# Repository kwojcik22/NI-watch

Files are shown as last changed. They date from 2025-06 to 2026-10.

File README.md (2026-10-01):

# NI-watch

NI-watch is an embedded watch project based on the STM32F0 MCU family. The firmware is designed for a custom hardware platform with RTC support, button input, LED feedback, alarm management, and UART-based debug logging.

## Post-production Images

  Top and bottom photos exported from the post-production media folder:

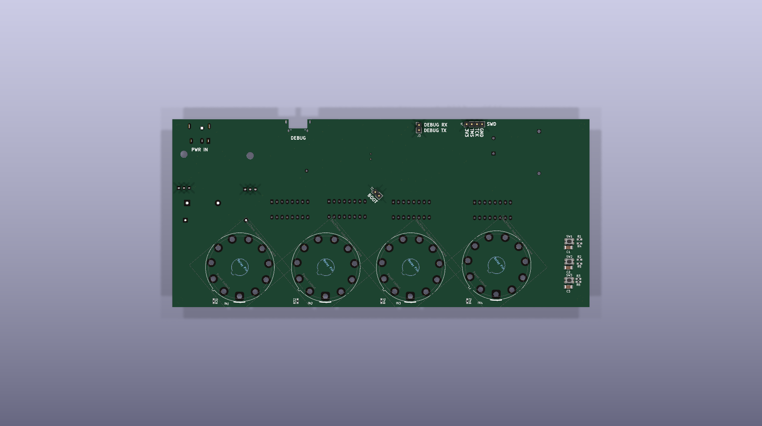
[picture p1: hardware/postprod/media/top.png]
Top view
  

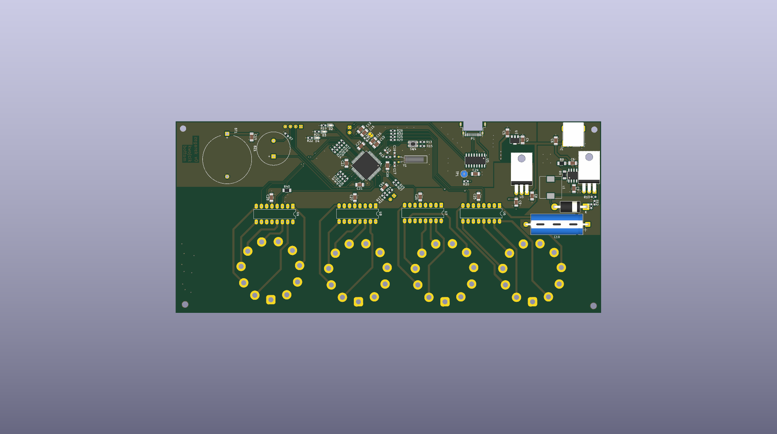
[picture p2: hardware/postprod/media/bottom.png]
Bottom view
  

## Project Structure

A compact overview of the main repository layout:

```text
NI-watch/
├── hardware/
│   ├── doc/
│   └── zegarek/
│       ├── fp-lib-table
│       ├── jlcpcb/
│       │   └── production_files/
│       ├── Library.pretty/
│       ├── MCU.kicad_sch
│       ├── NIXIE.kicad_sch
│       ├── PWR_MNG.kicad_sch
│       ├── zegarek.kicad_pcb
│       ├── zegarek.kicad_prl
│       ├── zegarek.kicad_pro
│       ├── zegarek.kicad_sch
├── README.md
└── software/
    └── TheWatch/
        ├── Core/
        │   ├── Inc/
        │   │   ├── bsp/
        │   │   ├── logger/
        │   │   └── Manager/
        │   └── Src/
        ├── Debug/
        ├── Drivers/
        ├── STM32F091RCTX_FLASH.ld
        ├── TheWatch Debug.launch
        └── TheWatch.ioc
```

The main firmware path is `software/TheWatch/Core/`, where the primary application, peripheral drivers, and helpers are located.

## Hardware Status

The `hardware/` folder contains the KiCad board project and the JLCPCB manufacturing export data for the watch design.

- `hardware/zegarek/zegarek.kicad_pcb` is the PCB layout file.
- The project includes additional schematic sheets for the MCU and power sections: `MCU.kicad_sch`, `NIXIE.kicad_sch`, and `PWR_MNG.kicad_sch`.
- `hardware/zegarek/Library.pretty/` contains custom local footprint libraries used by the design.
- `hardware/zegarek/jlcpcb/` contains fabrication outputs and assembly data exported for JLCPCB.
  - `hardware/zegarek/jlcpcb/production_files/gerber.zip` contains the generated Gerber files for board manufacturing.
  - `hardware/zegarek/jlcpcb/production_files/` contains the exported BOM and CPL files for assembly.

## MCU Peripherals

The table below lists only the MCU peripherals used by the firmware and their primary roles.

| Peripheral | Usage | Pins / Notes |
|---|---|---|
| RTC | Timekeeping, Alarm A | on-chip RTC |
| GPIO (Buttons) | User input (short/long press) | USER: `GPIOA/B` |
| LEDs | debug feedback & heartbeat | `GPIO_LED0/1/2` |
| UART | Debug logging (logger) | USART (see `usart.c`) |
| Timers | Heartbeat, alarm buzzer and non-blocking timers | TIMx (system timers) |

## Features

- 24-hour RTC operation using the on-chip RTC peripheral
- Alarm support using RTC Alarm A
- Button press detection with short press and long press events
- LED toggling for user feedback and heartbeat status
- UART logging for debug and runtime information

## User Interaction

### Buttons

- Blue button (configured on GPIOC pin 13)
  - Short press: read current RTC time and print it to the logger
  - Long press: set the RTC alarm to one minute ahead of the current time and log the alarm value
- Additional buttons on GPIOA and GPIOB toggle onboard LEDs for quick manual feedback

### LEDs

- LEDs connected to `GPIO_LED0`, `GPIO_LED1`, and `GPIO_LED2` toggle when their respective buttons are pressed
- `LD2` is toggled periodically by a non-blocking timer to provide a simple heartbeat indicator

## RTC and Alarm Behavior

- RTC is initialized with default time and date values
- Alarm A is enabled at startup and can be updated by user input
- Alarm behavior and interrupt handling are logged through the UART debug logger

## Debugging and Logging

- Logging is implemented through `logger/logger.h` and `logger/logger.c`
- Log levels include `INFO`, `WARN`, `ERROR`, and `DEBUG`
- The firmware prints time reads, alarm configuration, button events, and interrupt notices

## Build Notes

- The firmware is built using STM32Cube-generated HAL code and project files
- The target MCU is an STM32F091RCTX device
- `software/TheWatch/STM32F091RCTX_FLASH.ld` contains the linker script for flash layout

## Notes

This README describes the current firmware behavior as implemented in the provided source files. The project is a work in progress and can be extended with additional watch features such as display output, time setting via buttons

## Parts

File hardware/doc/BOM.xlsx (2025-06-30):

Reference | Value | Datasheet | Footprint | Qty | DNP
POJEMNOŚCI
C1 | 100nF | ~ | Capacitor_SMD:C_1206_3216Metric_Pad1.33x1.80mm_HandSolder | 1 | OK.
C2 | 1nF | ~ | Capacitor_SMD:C_1206_3216Metric_Pad1.33x1.80mm_HandSolder | 1 | OK.
C3 | 4u7 250V MPEM-4U7R27.5/250 | https://www.tme.eu/pl/details/mpem-4u7r27.5_250/kondensatory-foliowe-tht/sr-passives/ | Capacitor_THT:CP_Axial_L25.0mm_D10.0mm_P30.00mm_Horizontal | 1 | OK.
PÓŁPRZEWODNIKI
D1 | UF5400 | https://www.tme.eu/pl/details/uf4007-dio/diody-uniwersalne-tht/diotec-semiconductor/uf4007/ | Diode_THT:D_DO-201AD_P15.24mm_Horizontal | 1 | OK.
Q1 | IRF740PBF | https://www.tme.eu/pl/details/irf740pbf/tranzystory-z-kanalem-n-tht/vishay/ | Package_TO_SOT_THT:TO-220-3_Vertical | 1 | OK.
KONEKTORY
J1 | Conn_01x02_Socket | ~ | Connector:Banana_Jack_2Pin | 1 | OK.
J2 | Conn_01x02_Socket | ~ | Connector:Banana_Jack_2Pin | 1 | OK.
INDUKCYJNE
L1 | 100uH smd 800mA SD8328-101-R | https://www.tme.eu/pl/details/sd8328-101-r/dlawiki-smd-mocy/eaton-electronics/ | Inductor_SMD:L_10.4x10.4_H4.8 | 1 | OK.
REZYSTORY
R1 | 0R22 thic film prec. | https://www.tme.eu/pl/details/cs1206-0.22r-1%25/rezystory-smd/royal-ohm/cs06w4f220lt5e/ | Resistor_SMD:R_1206_3216Metric_Pad1.30x1.75mm_HandSolder | 1 | OK.
R2 | 180 | ~ | Resistor_SMD:R_0805_2012Metric | 1 | OK.
R3 | 330 | ~ | Resistor_SMD:R_0805_2012Metric_Pad1.20x1.40mm_HandSolder | 1 | OK.
R4 | 150k | ~ | Resistor_SMD:R_0805_2012Metric_Pad1.20x1.40mm_HandSolder | 1 | OK.
R5 | 1k | ~ | Resistor_SMD:R_0805_2012Metric_Pad1.20x1.40mm_HandSolder | 1 | OK.
UKŁADY SCALONE
U1 | MC34063ADR | https://www.tme.eu/pl/details/mc34063adr/regulatory-napiecia-uklady-dc-dc/texas-instruments/ | Package_SO:SOIC-8_3.9x4.9mm_P1.27mm | 1 | OK.
MECHANICZNE
 | dystans m3 | https://www.tme.eu/pl/details/fix-mae-15tv/kolki-montazowe-plastikowe/fix-fasten/ |  | 4 | OK.
 | śrubka M3 | _ |  | 5 | OK.
 | radiator M3 | https://www.tme.eu/pl/details/ua17-to220/radiatory/fischer-elektronik/sk13-35-al-220/ |  | 1 | OK.

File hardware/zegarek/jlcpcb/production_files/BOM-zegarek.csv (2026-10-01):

Comment | Designator | Footprint | LCSC | Quantity
Battery_Cell | BT1 | BatteryHolder_MYOUNG_BS-07-A1BJ001_CR2032 | C964750 | 1
Buzzer | BZ1 | MagneticBuzzer_StarMicronics_HMB |  | 1
100n | C1,C12,C14,C16,C19,C2,C20,C21,C22,C23,C24,C25,C26,C27,C28,C3,C5,C9 | C_1206_3216Metric_Pad1.33x1.80mm_HandSolder | C152824 | 18
4u7 250V | C10 | CP_Axial_L25.0mm_D10.0mm_P30.00mm_Horizontal |  | 1
10u | C11,C15 | C_1206_3216Metric_Pad1.33x1.80mm_HandSolder | C49326738 | 2
100n | C13 | C_0603_1608Metric_Pad1.08x0.95mm_HandSolder | C1590 | 1
4.3p | C17,C18 | C_0603_1608Metric_Pad1.08x0.95mm_HandSolder | C424850 | 2
0.33u | C4,C8 | C_1206_3216Metric_Pad1.33x1.80mm_HandSolder | C274377 | 2
100nF | C6 | C_1206_3216Metric_Pad1.33x1.80mm_HandSolder | C152824 | 1
1nF | C7 | C_1206_3216Metric_Pad1.33x1.80mm_HandSolder | C49326757 | 1
UF4007 | D1 | D_DO-201AD_P15.24mm_Horizontal | C54426167 | 1
LED | D2 | LED_0603_1608Metric_Pad1.05x0.95mm_HandSolder | C89811 | 1
LED | D3 | LED_0603_1608Metric_Pad1.05x0.95mm_HandSolder | C2286 | 1
LED | D4 | LED_0603_1608Metric_Pad1.05x0.95mm_HandSolder | C2288 | 1
BLM18AG121SN1 | FB1 | L_0603_1608Metric_Pad1.05x0.95mm_HandSolder | C76892 | 1
~ | IN1 | IN-14 NIXIE TUBE |  | 1
~ | IN2 | IN-14 NIXIE TUBE |  | 1
~ | IN3 | IN-14 NIXIE TUBE |  | 1
~ | IN4 | IN-14 NIXIE TUBE |  | 1
Barrel_Jack_MountingPin | J1 | BarrelJack_CUI_PJ-079BH_Horizontal |  | 1
Conn_01x02 | J2,J3 | PinHeader_1x02_P2.54mm_Vertical | C86471 | 2
Conn_01x04 | J4 | PinHeader_1x04_P2.54mm_Vertical | C124378 | 1
Jumper_2_Small_Bridged | JP1 | SolderJumper-2_P1.3mm_Bridged_RoundedPad1.0x1.5mm |  | 1
100uH | L1 | L_10.4x10.4_H4.8 | C2045483 | 1
USB_C_Plug_USB2.0 | P1 | USB_C_Receptacle_Amphenol_12401948E412A | C53185062 | 1
IRF740 | Q1 | TO-220-3_Horizontal_TabUp | C358408 | 1
1k | R1,R12,R13,R3,R7 | R_0603_1608Metric_Pad0.98x0.95mm_HandSolder | C2074140 | 5
330 | R10 | R_0603_1608Metric_Pad0.98x0.95mm_HandSolder | C23138 | 1
150k | R11 | R_0603_1608Metric_Pad0.98x0.95mm_HandSolder | C22807 | 1
10k | R14,R16 | R_0603_1608Metric_Pad0.98x0.95mm_HandSolder | C15401 | 2
4k7 | R15,R20,R4,R5,R6 | R_0603_1608Metric_Pad0.98x0.95mm_HandSolder | C3152147 | 5
510k | R17 | R_0603_1608Metric_Pad0.98x0.95mm_HandSolder | C23192 | 1
220 | R18,R19,R21,R22 | R_0603_1608Metric_Pad0.98x0.95mm_HandSolder | C54920883 | 4
1k | R2 | R_0603_1608Metric_Pad0.98x0.95mm_HandSolder |  | 1
100 | R23,R24,R25,R26,R27,R28,R29,R30,R33,R34,R35,R36,R37,R38,R39 | R_0603_1608Metric_Pad0.98x0.95mm_HandSolder | C3152153 | 15
15k | R31,R32,R41,R42 | R_0603_1608Metric_Pad0.98x0.95mm_HandSolder | C22809 | 4
100 | R40 | R_1206_3216Metric_Pad1.30x1.75mm_HandSolder | C17901 | 1
0R22 | R8 | R_1206_3216Metric_Pad1.30x1.75mm_HandSolder |  | 1
180 | R9 | R_1206_3216Metric_Pad1.30x1.75mm_HandSolder | C17924 | 1
SW_Push | SW1 | SW_Push_1P1T_NO_CK_KMR2 |  | 1
SW_Push | SW2 | SW_Push_1P1T_NO_CK_KMR2 |  | 1
SW_Push | SW3 | SW_Push_1P1T_NO_CK_KMR2 |  | 1
SW_Push | SW4 | SW_Push_1P1T_NO_CK_KMR2 |  | 1
DEBUG RST | TP1 | TestPoint_Loop_D2.60mm_Drill0.9mm_Beaded |  | 1
DI78L3.3UAB | U1 | SOT-89-3 |  | 1
MC34063AD | U2 | SOIC-8_3.9x4.9mm_P1.27mm | C2873086 | 1
L7805ACV | U3 | TO-220-3_Horizontal_TabUp | C192854 | 1
STM32F091RCTx | U4 | LQFP-64_10x10mm_P0.5mm | C89056 | 1
CH340C | U5 | SOIC-16_3.9x9.9mm_P1.27mm | C84681 | 1
74141 | U6 | CERDIP-16_W7.62mm_SideBrazed_LongPads |  | 1
74141 | U7 | CERDIP-16_W7.62mm_SideBrazed_LongPads |  | 1
74141 | U8 | CERDIP-16_W7.62mm_SideBrazed_LongPads |  | 1
74141 | U9 | CERDIP-16_W7.62mm_SideBrazed_LongPads |  | 1
32.768kHz | Y1 | Crystal_AT310_D3.0mm_L10.0mm_Horizontal | C2236 | 1

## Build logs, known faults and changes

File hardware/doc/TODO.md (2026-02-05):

[ ] - zmieniono C2 na mniejszy (biały chyba 200pF), czy 100V było też na 200p czy tylko na 100p?
[ ] - 150k R4 zostaje 150k
[ ] - 1k R5 dopasować na potencjometrze != 0ohm

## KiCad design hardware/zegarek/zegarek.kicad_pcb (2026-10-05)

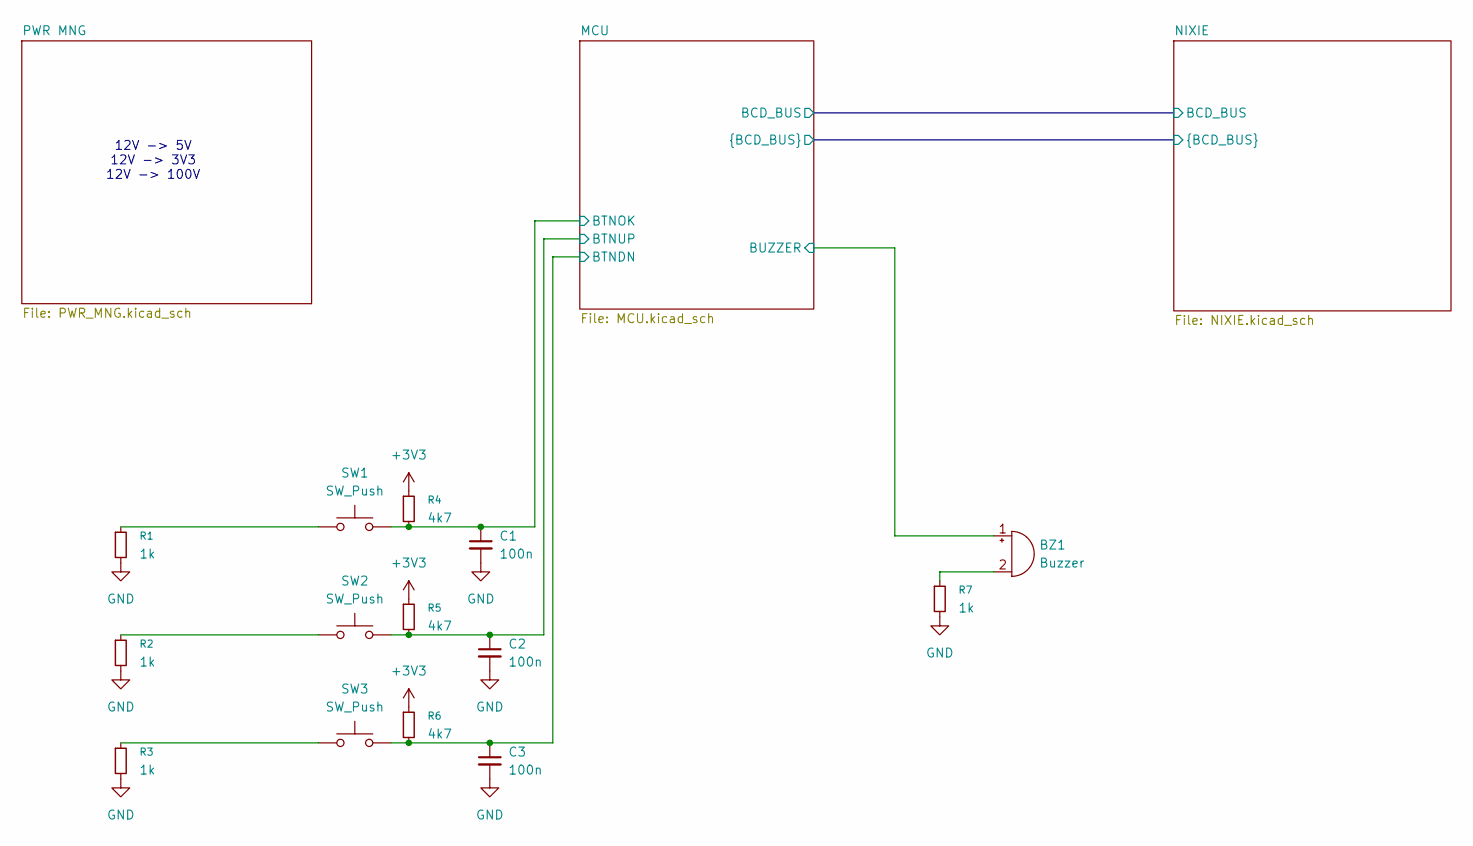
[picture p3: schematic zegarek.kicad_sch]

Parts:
BZ1: Buzzer; MagneticBuzzer_StarMicronics_HMB
C1, C2, C3: 100n; C_1206_3216Metric_Pad1.33x1.80mm_HandSolder; LCSC C152824
R1, R3, R7: 1k; R_0603_1608Metric_Pad0.98x0.95mm_HandSolder; LCSC C2074140
R2: 1k; R_0603_1608Metric_Pad0.98x0.95mm_HandSolder
R4, R5, R6: 4k7; R_0603_1608Metric_Pad0.98x0.95mm_HandSolder; LCSC C3152147
SW1, SW2, SW3: SW_Push; SW_Push_1P1T_NO_CK_KMR2

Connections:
+3V3: R4.1, R5.1, R6.1; also elsewhere on the board
/MCU/BTNDN: C3.1, R6.2, SW3.2; also elsewhere on the board
/MCU/BTNOK: C1.1, R4.2, SW1.2; also elsewhere on the board
/MCU/BTNUP: C2.1, R5.2, SW2.2; also elsewhere on the board
/MCU/BUZZER: BZ1.1 (+); also elsewhere on the board
GND: C1.2, C2.2, C3.2, R1.2, R2.2, R3.2, R7.2; also elsewhere on the board
unnamed: BZ1.2 (-), R7.1
unnamed: R1.1, SW1.1
unnamed: R2.1, SW2.1
unnamed: R3.1, SW3.1

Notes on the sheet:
12V -> 5V 12V -> 3V3 12V -> 100V

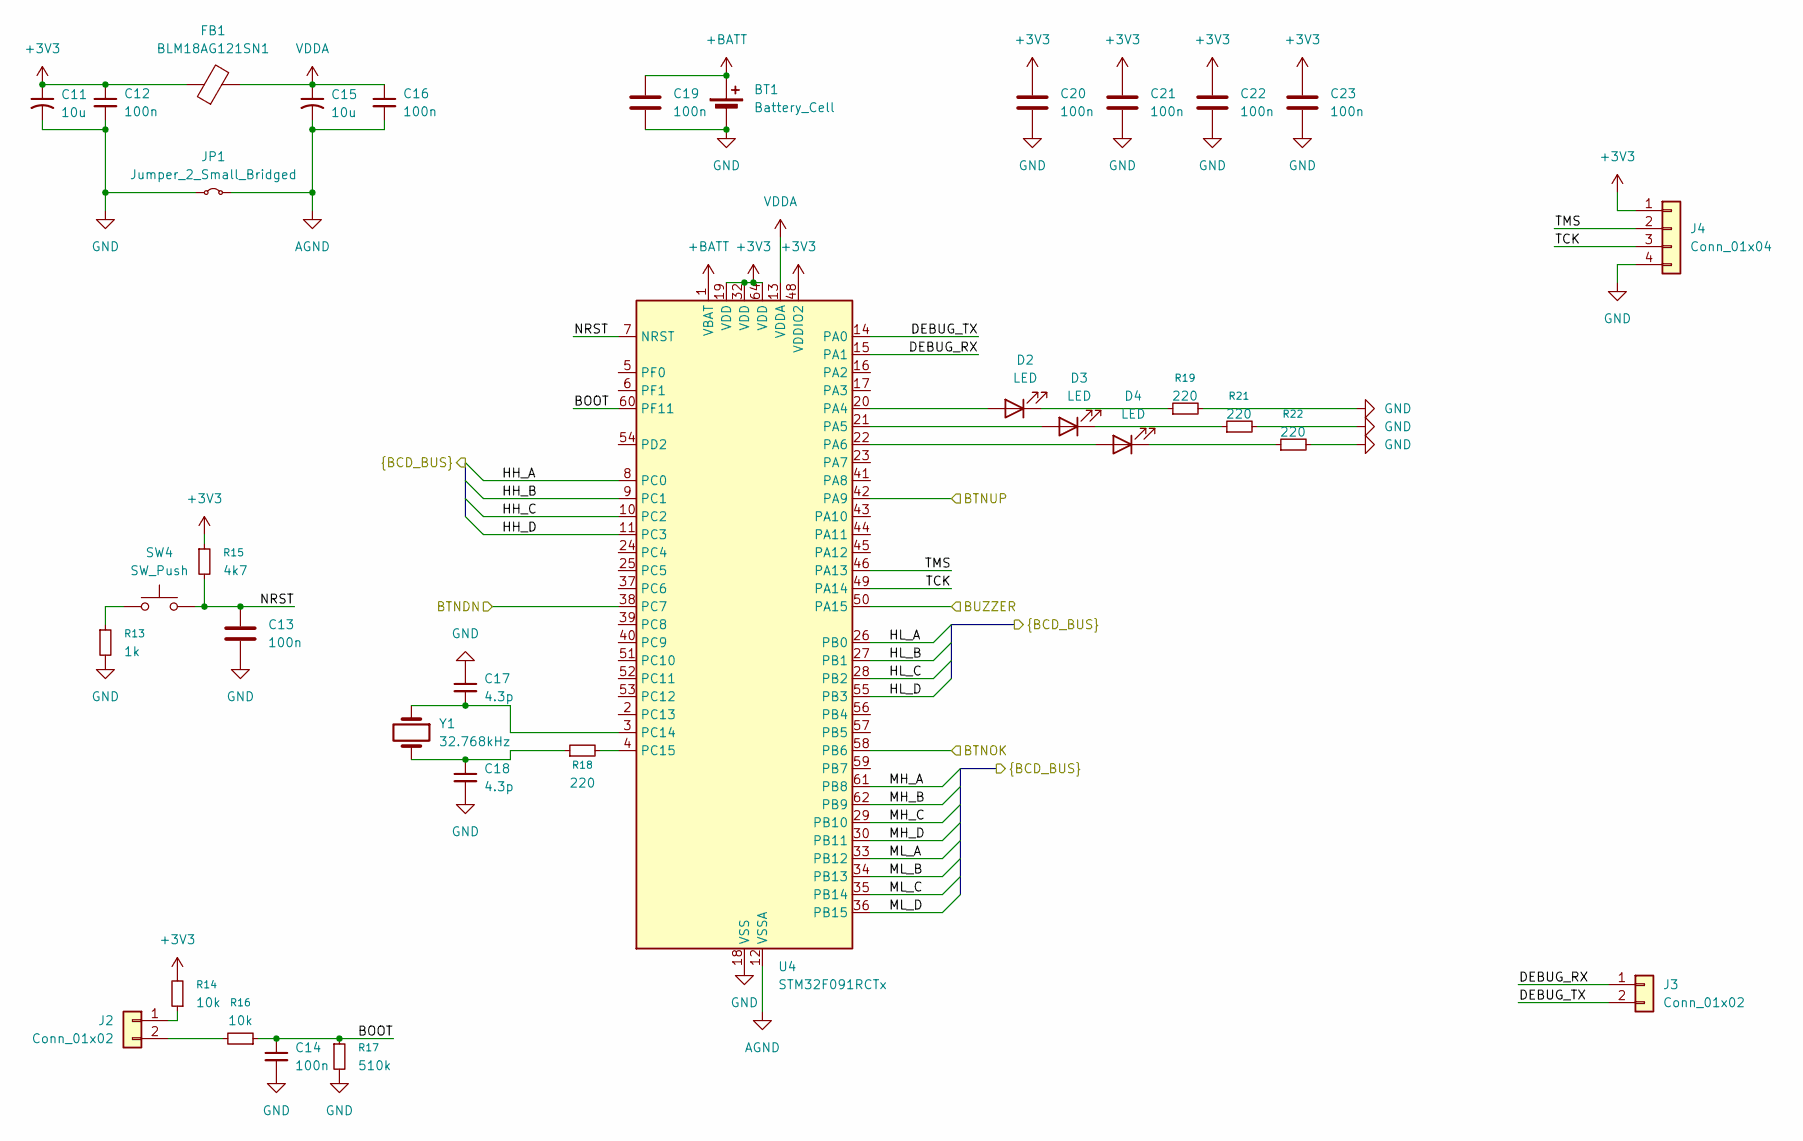
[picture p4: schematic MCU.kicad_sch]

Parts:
BT1: Battery_Cell; BatteryHolder_MYOUNG_BS-07-A1BJ001_CR2032; LCSC C964750
C11, C15: 10u; C_1206_3216Metric_Pad1.33x1.80mm_HandSolder; LCSC C49326738
C12, C14, C16, C19, C20, C21, C22, C23: 100n; C_1206_3216Metric_Pad1.33x1.80mm_HandSolder; LCSC C152824
C13: 100n; C_0603_1608Metric_Pad1.08x0.95mm_HandSolder; LCSC C1590
C17, C18: 4.3p; C_0603_1608Metric_Pad1.08x0.95mm_HandSolder; LCSC C424850
D2: LED; LED_0603_1608Metric_Pad1.05x0.95mm_HandSolder; LCSC C89811
D3: LED; LED_0603_1608Metric_Pad1.05x0.95mm_HandSolder; LCSC C2286
D4: LED; LED_0603_1608Metric_Pad1.05x0.95mm_HandSolder; LCSC C2288
FB1: BLM18AG121SN1; L_0603_1608Metric_Pad1.05x0.95mm_HandSolder; LCSC C76892
J2, J3: Conn_01x02; PinHeader_1x02_P2.54mm_Vertical; LCSC C86471
J4: Conn_01x04; PinHeader_1x04_P2.54mm_Vertical; LCSC C124378
JP1: Jumper_2_Small_Bridged; SolderJumper-2_P1.3mm_Bridged_RoundedPad1.0x1.5mm
R13: 1k; R_0603_1608Metric_Pad0.98x0.95mm_HandSolder; LCSC C2074140
R14, R16: 10k; R_0603_1608Metric_Pad0.98x0.95mm_HandSolder; LCSC C15401
R15: 4k7; R_0603_1608Metric_Pad0.98x0.95mm_HandSolder; LCSC C3152147
R17: 510k; R_0603_1608Metric_Pad0.98x0.95mm_HandSolder; LCSC C23192
R18, R19, R21, R22: 220; R_0603_1608Metric_Pad0.98x0.95mm_HandSolder; LCSC C54920883
SW4: SW_Push; SW_Push_1P1T_NO_CK_KMR2
U4: STM32F091RCTx; LQFP-64_10x10mm_P0.5mm; LCSC C89056
Y1: 32.768kHz; Crystal_AT310_D3.0mm_L10.0mm_Horizontal; LCSC C2236

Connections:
+3V3: C11.1, C12.1, C20.1, C21.1, C22.1, C23.1, FB1.1, J4.1, R14.2, R15.1, U4.19 (VDD), U4.32 (VDD), U4.48 (VDDIO2), U4.64 (VDD); also elsewhere on the board
+BATT: BT1.1 (+), C19.1, U4.1 (VBAT)
/MCU/BOOT: C14.1, R16.1, R17.1, U4.60 (PF11)
/MCU/BTNDN: U4.38 (PC7); also elsewhere on the board
/MCU/BTNOK: U4.58 (PB6); also elsewhere on the board
/MCU/BTNUP: U4.42 (PA9); also elsewhere on the board
/MCU/BUZZER: U4.50 (PA15); also elsewhere on the board
/MCU/DEBUG_RX: J3.1, U4.15 (PA1)
/MCU/DEBUG_TX: J3.2, U4.14 (PA0)
/MCU/HH_A: U4.8 (PC0); also elsewhere on the board
/MCU/HH_B: U4.9 (PC1); also elsewhere on the board
/MCU/HH_C: U4.10 (PC2); also elsewhere on the board
/MCU/HH_D: U4.11 (PC3); also elsewhere on the board
/MCU/HL_A: U4.26 (PB0); also elsewhere on the board
/MCU/HL_B: U4.27 (PB1); also elsewhere on the board
/MCU/HL_C: U4.28 (PB2); also elsewhere on the board
/MCU/HL_D: U4.55 (PB3); also elsewhere on the board
/MCU/MH_A: U4.61 (PB8); also elsewhere on the board
/MCU/MH_B: U4.62 (PB9); also elsewhere on the board
/MCU/MH_C: U4.29 (PB10); also elsewhere on the board
/MCU/MH_D: U4.30 (PB11); also elsewhere on the board
/MCU/ML_A: U4.33 (PB12); also elsewhere on the board
/MCU/ML_B: U4.34 (PB13); also elsewhere on the board
/MCU/ML_C: U4.35 (PB14); also elsewhere on the board
/MCU/ML_D: U4.36 (PB15); also elsewhere on the board
/MCU/NRST: C13.1, R15.2, SW4.2, U4.7 (NRST)
/MCU/TCK: J4.3, U4.49 (PA14)
/MCU/TMS: J4.2, U4.46 (PA13)
AGND: C15.2, C16.2, JP1.2 (B), U4.12 (VSSA)
GND: BT1.2 (-), C11.2, C12.2, C13.2, C14.2, C17.1, C18.2, C19.2, C20.2, C21.2, C22.2, C23.2, J4.4, JP1.1 (A), R13.2, R17.2, R19.2, R21.2, R22.2, U4.18 (VSS), U4.31 (VSS), U4.47 (VSS), U4.63 (VSS); also elsewhere on the board
unnamed: C18.1, R18.1, Y1.2
unnamed: D2.2 (A), U4.20 (PA4)
unnamed: D2.1 (K), R19.1
unnamed: D3.2 (A), U4.21 (PA5)
unnamed: D3.1 (K), R21.1
unnamed: D4.2 (A), U4.22 (PA6)
unnamed: D4.1 (K), R22.1
unnamed: J2.1, R14.1
unnamed: J2.2, R16.2
unnamed: R13.1, SW4.1
unnamed: C17.2, U4.3 (PC14), Y1.1
unnamed: R18.2, U4.4 (PC15)
VDDA: C15.1, C16.1, FB1.2, U4.13 (VDDA)

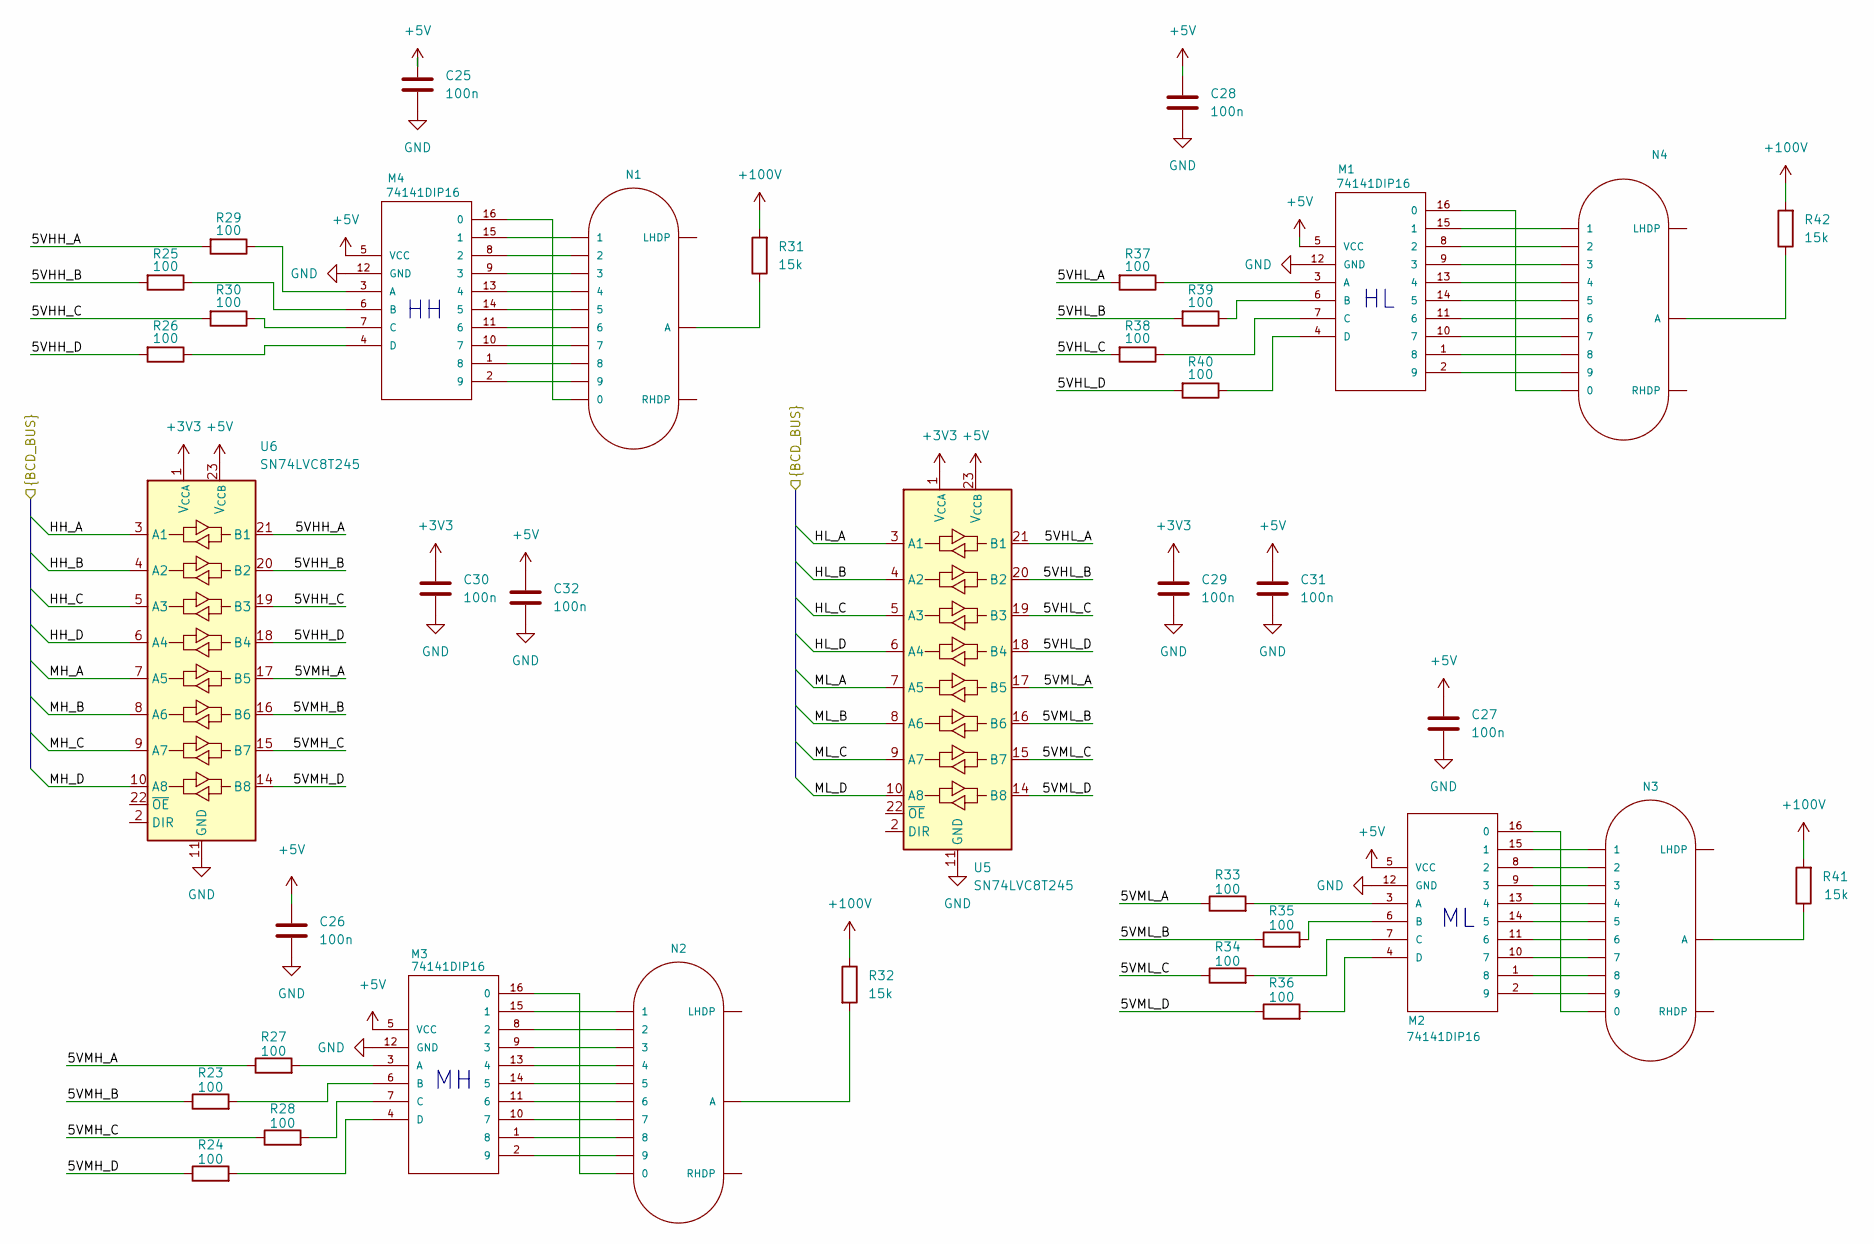
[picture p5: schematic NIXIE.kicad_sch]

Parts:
C25, C26, C27, C28, C29, C30, C31, C32: 100n; C_1206_3216Metric_Pad1.33x1.80mm_HandSolder; LCSC C152824
M1, M2, M3, M4: 74141DIP16; nixiemisc-DIP16
N1, N2, N3, N4: IN-14; nixies-us-IN-14
R23, R24, R25, R26, R27, R28, R29, R30, R33, R34, R35, R36, R37, R38, R39: 100; R_0603_1608Metric_Pad0.98x0.95mm_HandSolder; LCSC C3152153
R31, R32, R41, R42: 15k; R_0603_1608Metric_Pad0.98x0.95mm_HandSolder; LCSC C22809
R40: 100; R_1206_3216Metric_Pad1.30x1.75mm_HandSolder; LCSC C17901
U5, U6: SN74LVC8T245; SSOP-24_3.9x8.7mm_P0.635mm

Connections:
+3V3: C29.1, C30.1, U5.1 (V_{CCA}), U6.1 (V_{CCA}); also elsewhere on the board
+5V: C25.1, C26.1, C27.1, C28.1, C31.1, C32.1, M1.5 (VCC), M2.5 (VCC), M3.5 (VCC), M4.5 (VCC), U5.23 (V_{CCB}), U5.24 (V_{CCB}), U6.23 (V_{CCB}), U6.24 (V_{CCB}); also elsewhere on the board
+100V: R31.2, R32.1, R41.2, R42.2; also elsewhere on the board
/MCU/HH_A: U6.3 (A1); also elsewhere on the board
/MCU/HH_B: U6.4 (A2); also elsewhere on the board
/MCU/HH_C: U6.5 (A3); also elsewhere on the board
/MCU/HH_D: U6.6 (A4); also elsewhere on the board
/MCU/HL_A: U5.3 (A1); also elsewhere on the board
/MCU/HL_B: U5.4 (A2); also elsewhere on the board
/MCU/HL_C: U5.5 (A3); also elsewhere on the board
/MCU/HL_D: U5.6 (A4); also elsewhere on the board
/MCU/MH_A: U6.7 (A5); also elsewhere on the board
/MCU/MH_B: U6.8 (A6); also elsewhere on the board
/MCU/MH_C: U6.9 (A7); also elsewhere on the board
/MCU/MH_D: U6.10 (A8); also elsewhere on the board
/MCU/ML_A: U5.7 (A5); also elsewhere on the board
/MCU/ML_B: U5.8 (A6); also elsewhere on the board
/MCU/ML_C: U5.9 (A7); also elsewhere on the board
/MCU/ML_D: U5.10 (A8); also elsewhere on the board
/NIXIE/5VHH_A: R29.2, U6.21 (B1)
/NIXIE/5VHH_B: R25.2, U6.20 (B2)
/NIXIE/5VHH_C: R30.2, U6.19 (B3)
/NIXIE/5VHH_D: R26.2, U6.18 (B4)
/NIXIE/5VHL_A: R37.2, U5.21 (B1)
/NIXIE/5VHL_B: R39.2, U5.20 (B2)
/NIXIE/5VHL_C: R38.2, U5.19 (B3)
/NIXIE/5VHL_D: R40.2, U5.18 (B4)
/NIXIE/5VMH_A: R27.1, U6.17 (B5)
/NIXIE/5VMH_B: R23.1, U6.16 (B6)
/NIXIE/5VMH_C: R28.1, U6.15 (B7)
/NIXIE/5VMH_D: R24.1, U6.14 (B8)
/NIXIE/5VML_A: R33.1, U5.17 (B5)
/NIXIE/5VML_B: R35.1, U5.16 (B6)
/NIXIE/5VML_C: R34.1, U5.15 (B7)
/NIXIE/5VML_D: R36.1, U5.14 (B8)
GND: C25.2, C26.2, C27.2, C28.2, C29.2, C30.2, C31.2, C32.2, M1.12 (GND), M2.12 (GND), M3.12 (GND), M4.12 (GND), U5.11 (GND), U5.12 (GND), U5.13 (GND), U6.11 (GND), U6.12 (GND), U6.13 (GND); also elsewhere on the board
unnamed: M1.16 (0), N4.0
unnamed: M1.15 (1), N4.1
unnamed: M1.8 (2), N4.2
unnamed: M1.9 (3), N4.3
unnamed: M1.13 (4), N4.4
unnamed: M1.14 (5), N4.5
unnamed: M1.11 (6), N4.6
unnamed: M1.10 (7), N4.7
unnamed: M1.1 (8), N4.8
unnamed: M1.2 (9), N4.9
unnamed: M1.3 (A), R37.1
unnamed: M1.6 (B), R39.1
unnamed: M1.7 (C), R38.1
unnamed: M1.4 (D), R40.1
unnamed: M2.16 (0), N3.0
unnamed: M2.15 (1), N3.1
unnamed: M2.8 (2), N3.2
unnamed: M2.9 (3), N3.3
unnamed: M2.13 (4), N3.4
unnamed: M2.14 (5), N3.5
unnamed: M2.11 (6), N3.6
unnamed: M2.10 (7), N3.7
unnamed: M2.1 (8), N3.8
unnamed: M2.2 (9), N3.9
unnamed: M2.3 (A), R33.2
unnamed: M2.6 (B), R35.2
unnamed: M2.7 (C), R34.2
unnamed: M2.4 (D), R36.2
unnamed: M3.16 (0), N2.0
unnamed: M3.15 (1), N2.1
unnamed: M3.8 (2), N2.2
unnamed: M3.9 (3), N2.3
unnamed: M3.13 (4), N2.4
unnamed: M3.14 (5), N2.5
unnamed: M3.11 (6), N2.6
unnamed: M3.10 (7), N2.7
unnamed: M3.1 (8), N2.8
unnamed: M3.2 (9), N2.9
unnamed: M3.3 (A), R27.2
unnamed: M3.6 (B), R23.2
unnamed: M3.7 (C), R28.2
unnamed: M3.4 (D), R24.2
unnamed: M4.16 (0), N1.0
unnamed: M4.15 (1), N1.1
unnamed: M4.8 (2), N1.2
unnamed: M4.9 (3), N1.3
unnamed: M4.13 (4), N1.4
unnamed: M4.14 (5), N1.5
unnamed: M4.11 (6), N1.6
unnamed: M4.10 (7), N1.7
unnamed: M4.1 (8), N1.8
unnamed: M4.2 (9), N1.9
unnamed: M4.3 (A), R29.1
unnamed: M4.6 (B), R25.1
unnamed: M4.7 (C), R30.1
unnamed: M4.4 (D), R26.1
unnamed: N1.A, R31.1
unnamed: N2.A, R32.2
unnamed: N3.A, R41.1
unnamed: N4.A, R42.1

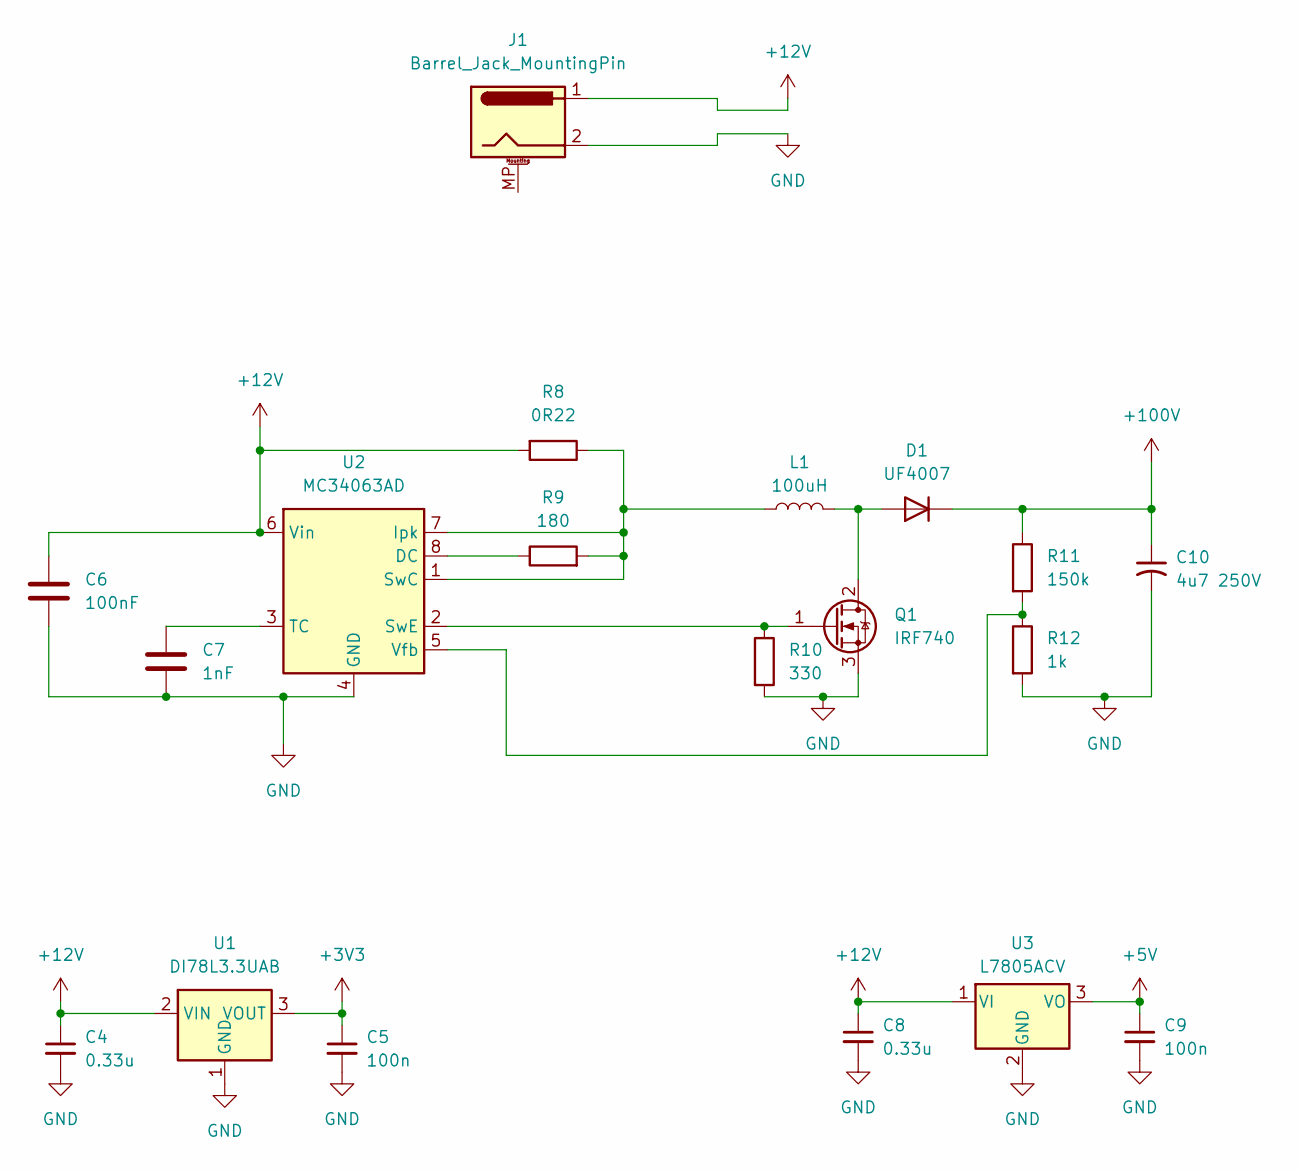
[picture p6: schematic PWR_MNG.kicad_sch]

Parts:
C4, C8: 0.33u; C_1206_3216Metric_Pad1.33x1.80mm_HandSolder; LCSC C274377
C5, C9: 100n; C_1206_3216Metric_Pad1.33x1.80mm_HandSolder; LCSC C152824
C6: 100nF; C_1206_3216Metric_Pad1.33x1.80mm_HandSolder; LCSC C152824
C7: 1nF; C_1206_3216Metric_Pad1.33x1.80mm_HandSolder; LCSC C49326757
C10: 4u7 250V; CP_Axial_L25.0mm_D10.0mm_P30.00mm_Horizontal
D1: UF4007; D_DO-201AD_P15.24mm_Horizontal; LCSC C54426167
J1: Barrel_Jack_MountingPin; BarrelJack_CUI_PJ-079BH_Horizontal
L1: 100uH; L_10.4x10.4_H4.8; LCSC C2045483
Q1: IRF740; TO-220-3_Horizontal_TabUp; LCSC C358408
R8: 0R22; R_1206_3216Metric_Pad1.30x1.75mm_HandSolder
R9: 180; R_1206_3216Metric_Pad1.30x1.75mm_HandSolder; LCSC C17924
R10: 330; R_0603_1608Metric_Pad0.98x0.95mm_HandSolder; LCSC C23138
R11: 150k; R_0603_1608Metric_Pad0.98x0.95mm_HandSolder; LCSC C22807
R12: 1k; R_0603_1608Metric_Pad0.98x0.95mm_HandSolder; LCSC C2074140
U1: DI78L3.3UAB; SOT-89-3
U2: MC34063AD; SOIC-8_3.9x4.9mm_P1.27mm; LCSC C2873086
U3: L7805ACV; TO-220-3_Horizontal_TabUp; LCSC C192854

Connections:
+3V3: C5.1, U1.3 (VOUT); also elsewhere on the board
+5V: C9.1, U3.3 (VO); also elsewhere on the board
+12V: C4.1, C6.2, C8.1, J1.1, R8.2, U1.2 (VIN), U2.6 (Vin), U3.1 (VI); also elsewhere on the board
+100V: C10.1, D1.1 (K), R11.1; also elsewhere on the board
GND: C4.2, C5.2, C6.1, C7.2, C8.2, C9.2, C10.2, J1.2, Q1.3 (S), R10.2, R12.2, U1.1 (GND), U2.4 (GND), U3.2 (GND); also elsewhere on the board
unnamed: D1.2 (A), L1.2, Q1.2 (D)
unnamed: Q1.1 (G), R10.1, U2.2 (SwE)
unnamed: R9.1, U2.8 (DC)
unnamed: L1.1, R8.1, R9.2, U2.1 (SwC), U2.7 (Ipk)
unnamed: C7.1, U2.3 (TC)
unnamed: R11.2, R12.1, U2.5 (Vfb)

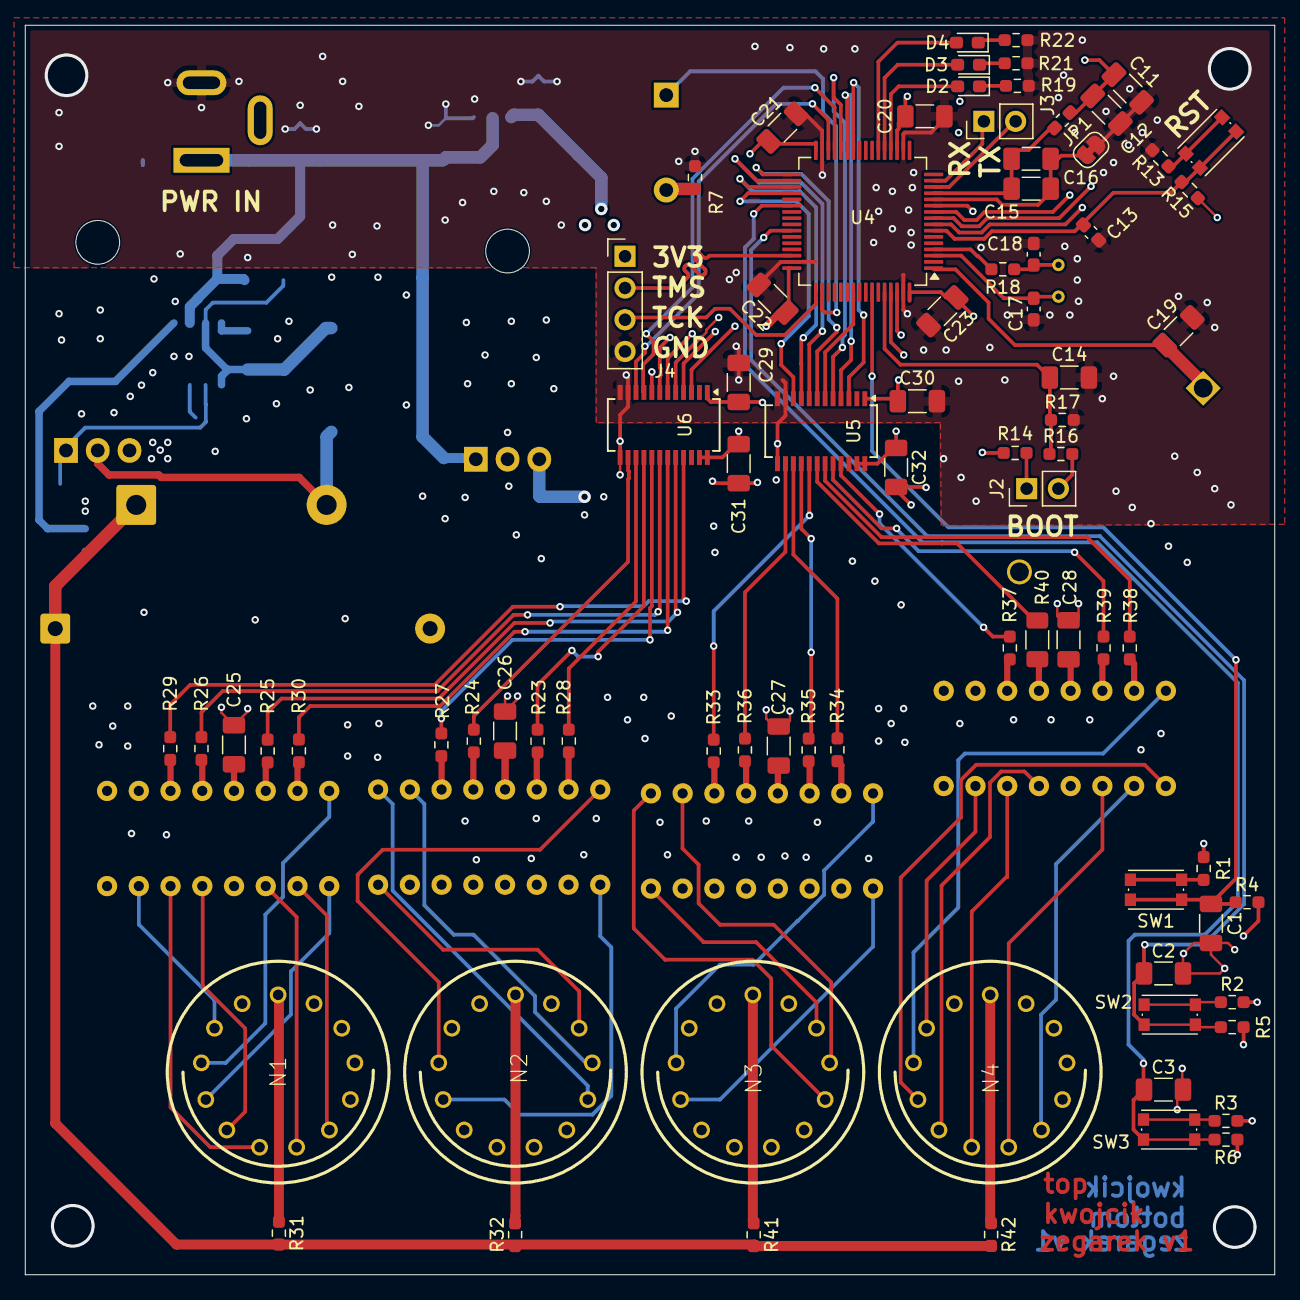
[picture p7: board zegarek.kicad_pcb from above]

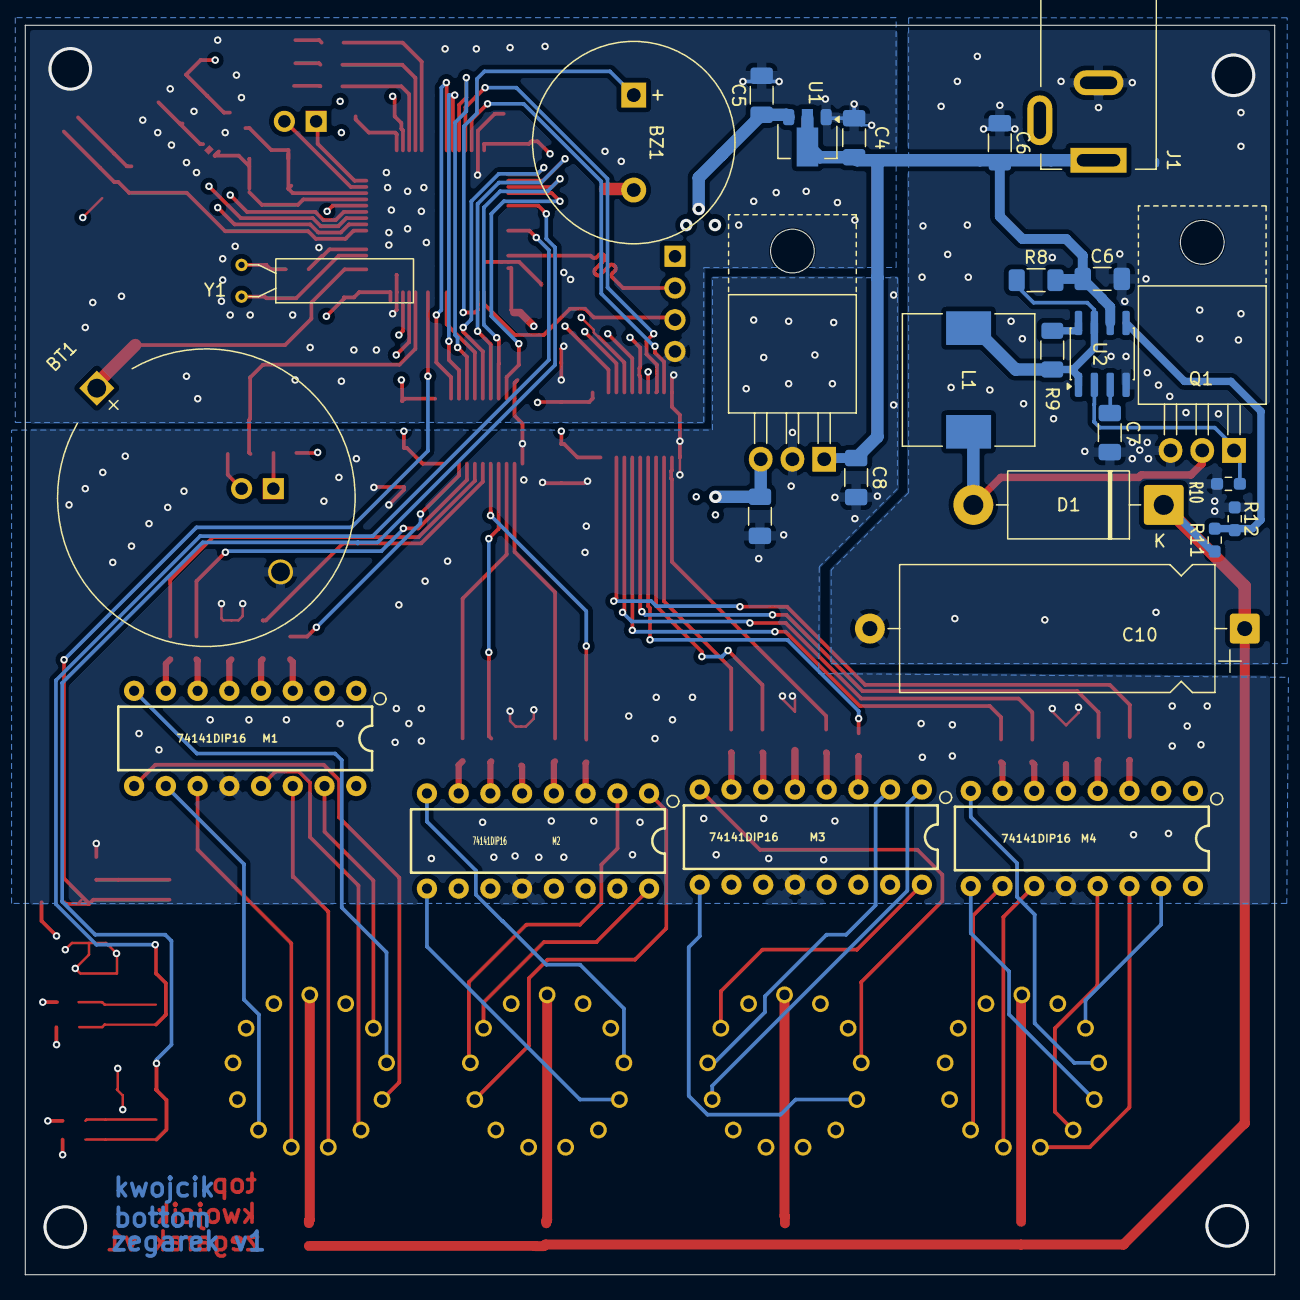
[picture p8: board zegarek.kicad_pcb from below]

Board: 4 copper layers, 100.0 x 100.0 mm, 106 parts (27 on the bottom side), 132 nets.

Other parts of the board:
C6#2: 100nF; C_1206_3216Metric_Pad1.33x1.80mm_HandSolder

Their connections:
+12V: C6#2.2; also elsewhere on the board
GND: C6#2.1; also elsewhere on the board

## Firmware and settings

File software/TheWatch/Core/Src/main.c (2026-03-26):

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
/* Includes ------------------------------------------------------------------*/
#include "main.h"
#include "rtc.h"
#include "usart.h"
#include "gpio.h"

/* USER CODE BEGIN Includes */
#include "bsp/buttons.h"
#include "bsp/RTC/Time.h"
#include "logger/logger.h"
#include "Manager/manager.h"
/* USER CODE END Includes */


void SystemClock_Config(void);
/**
  * @brief  The application entry point.
  * @retval int
  */
int main(void)
{
  /* MCU Configuration--------------------------------------------------------*/

  /* Reset of all peripherals, Initializes the Flash interface and the Systick. */
  HAL_Init();

  /* Configure the system clock */
  SystemClock_Config();

  /* Initialize all configured peripherals */
  MX_GPIO_Init();
  MX_USART2_UART_Init();
  MX_USART4_UART_Init();
  MX_RTC_Init();
  /* USER CODE BEGIN 2 */
  button_t Button_BLUE;
  init_Btn(&Button_BLUE, GPIOC, (1U << 13));

  RTC_SetAlarmBCD(&hrtc, 8U, 0U);
 // RTC_DisableAlarm();


  uint8_t hh = 0;
  uint8_t mm = 0;

  uint32_t timer = 0;
  /* USER CODE END 2 */

  /* Infinite loop */
  /* USER CODE BEGIN WHILE */
  while (1)
  {
	  Button_Pressed(&Button_BLUE);
	  if (HAL_GPIO_ReadPin(GPIOC, GPIO_BTNDN_Pin)){
		  HAL_GPIO_TogglePin(GPIO_LED0_GPIO_Port, GPIO_LED0_Pin);
	  }
	  if (HAL_GPIO_ReadPin(GPIOA, GPIO_BTNUP_Pin)){
		  HAL_GPIO_TogglePin(GPIO_LED1_GPIO_Port, GPIO_LED1_Pin);
	  }
	  if (HAL_GPIO_ReadPin(GPIOB, GPO_BTNOK_Pin)){
		  HAL_GPIO_TogglePin(GPIO_LED2_GPIO_Port, GPIO_LED2_Pin);
	  }

	  if(Button_BLUE.flags.long_press){
		  RTC_SetAlarmBCD(&hrtc, hh, mm+1);
		  log_printf(LOG_WARN,"alarm set to: %.2x:%.2x",hh,mm+1);
		  Button_BLUE.flags.long_press=0U;
	  }

	  if(Button_BLUE.flags.short_press){
		  RTC_ReadTimeBCD(&hh, &mm);
		  log_printf(LOG_INFO,"RTC: %.2x:%.2x",hh,mm);

		  Button_BLUE.flags.short_press=0U;
	  }

	  if(delay_nonblocking(&timer, 3000)){
		  HAL_GPIO_TogglePin(LD2_GPIO_Port, LD2_Pin);
	  }
    /* USER CODE END WHILE */

    /* USER CODE BEGIN 3 */
  }
  /* USER CODE END 3 */
}

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


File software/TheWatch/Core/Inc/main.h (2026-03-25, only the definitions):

#define B1_Pin GPIO_PIN_13
#define B1_GPIO_Port GPIOC
#define USART_TX_Pin GPIO_PIN_2
#define USART_TX_GPIO_Port GPIOA
#define USART_RX_Pin GPIO_PIN_3
#define USART_RX_GPIO_Port GPIOA
#define LD2_Pin GPIO_PIN_5
#define LD2_GPIO_Port GPIOA
#define GPIO_LED4_Pin GPIO_PIN_10
#define GPIO_LED4_GPIO_Port GPIOB
#define GPIO_BTNDN_Pin GPIO_PIN_7
#define GPIO_BTNDN_GPIO_Port GPIOC
#define GPIO_BTNUP_Pin GPIO_PIN_9
#define GPIO_BTNUP_GPIO_Port GPIOA
#define GPIO_LED0_Pin GPIO_PIN_10
#define GPIO_LED0_GPIO_Port GPIOA
#define TMS_Pin GPIO_PIN_13
#define TMS_GPIO_Port GPIOA
#define TCK_Pin GPIO_PIN_14
#define TCK_GPIO_Port GPIOA
#define GPIO_LED1_Pin GPIO_PIN_3
#define GPIO_LED1_GPIO_Port GPIOB
#define GPIO_LED3_Pin GPIO_PIN_4
#define GPIO_LED3_GPIO_Port GPIOB
#define GPIO_LED2_Pin GPIO_PIN_5
#define GPIO_LED2_GPIO_Port GPIOB
#define GPO_BTNOK_Pin GPIO_PIN_6
#define GPO_BTNOK_GPIO_Port GPIOB

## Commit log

2025-03-15 init Hw nixiepower
    [nixie_power.kicad_sch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]
2025-03-15 added doc and sink in pcb
    [BOM.xlsx, nixie_power.kicad_sch]
2025-03-15 links to those bought
    [BOM.xlsx, zegarek.csv]
2025-03-15 c1 pwr/gnd
    [nixie_power.kicad_sch, zegarek.kicad_pcb]
2025-03-16 ordered gerber
    [zegarek-B_Cu.gbr, zegarek-B_Mask.gbr, zegarek-B_Paste.gbr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]
2025-05-06 full BOM, mounted - verified footprints ok (- radiator hole)
    [BOM.xlsx]
2025-06-30 diode correction
    [BOM.xlsx, nixie_power.kicad_sch, zegarek.kicad_pcb]
2026-03-25 running prototype set
2026-03-26 prototype running
2026-07-30 page MCU and NIXIE done, nixiepwr changed name to PWR MNG
    [MCU.kicad_sch, NIXIE.kicad_sch, PWR_MNG.kicad_sch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]
2026-07-30 pwr page done
    [MCU.kicad_sch, NIXIE.kicad_sch, PWR_MNG.kicad_sch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]
2026-07-30 added status leds buttons and buzzer, 100V header deleted, footprints assigned
    [MCU.kicad_sch, NIXIE.kicad_sch, PWR_MNG.kicad_sch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]
2026-07-31 done placing footprins on pcb, started tracing pcb
    [MCU.kicad_sch, NIXIE.kicad_sch, PWR_MNG.kicad_sch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]
2026-08-03 signal traces done
    [zegarek.kicad_pcb]
2026-08-03 pwr tracing done
    [zegarek.kicad_pcb, zegarek.kicad_sch]
2026-08-04 added kicad postprod jobset and postprod files
    [BOM.csv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]
2026-08-05 jlc generated bom and grb+drill
    [BOM-zegarek.csv, MCU.kicad_sch, NIXIE.kicad_sch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]
2026-08-06 media added to readme, deleted postprod redundants
    [BOM.csv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]
2026-08-06 silk fixes
    [CPL-zegarek.csv, zegarek-CuBottom.gbr, zegarek-CuIn1.gbr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]
2026-10-01 new revision with fixes from prototype: level shift to mcu added, changed con footprints and debug usb deleted
    [BOM-zegarek.csv, MCU.kicad_sch, NIXIE.kicad_sch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]
2026-10-01 new board size organization
    [zegarek.kicad_pcb]
2026-10-01 tracing lamps
    [zegarek.kicad_pcb]
2026-10-02 tracing pcb
    [zegarek.kicad_pcb]
2026-10-05 changed dc connector footprint, DRCfixes done
    [zegarek.kicad_pcb]
2026-10-12 rerouting tubes order for proper display order
2026-10-20 correction changes, postprod files regenration,added OE and EN to MCU schematic
2026-11-09 footprint change for level shifters and postprod update

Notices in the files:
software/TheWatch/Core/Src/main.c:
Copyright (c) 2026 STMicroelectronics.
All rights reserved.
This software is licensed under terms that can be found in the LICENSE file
